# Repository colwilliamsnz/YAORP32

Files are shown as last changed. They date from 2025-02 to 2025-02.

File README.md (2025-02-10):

# YAORP32
 
## Yet Another Open Reflow Plate

A design for a solder reflow plate for SMD rework using commonly available aluminium 400W PTC (positive-temperature-coefficient) heating plate from AliExpress. Temperature is
determined using a K type thermocouple and read using a MAX6675/MAX31855. The PTC is driven by an SSR (solid state relay) using PWM and controlled by a PID. An ESP32 S3 Wroom 1 module is at the heart of the design and firmware is written in C++ for Arduino IDE.

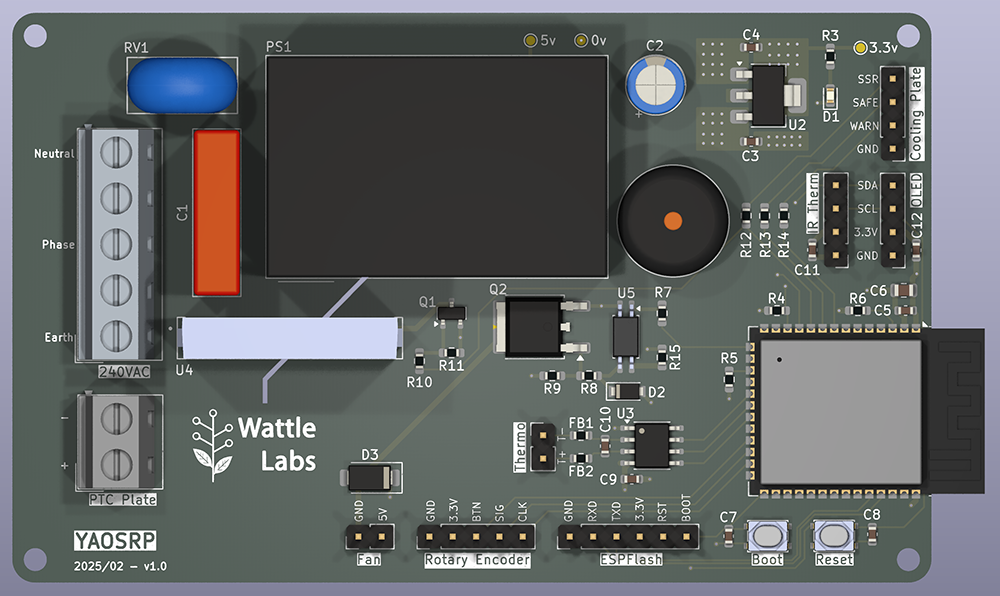
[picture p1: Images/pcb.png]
Prototype


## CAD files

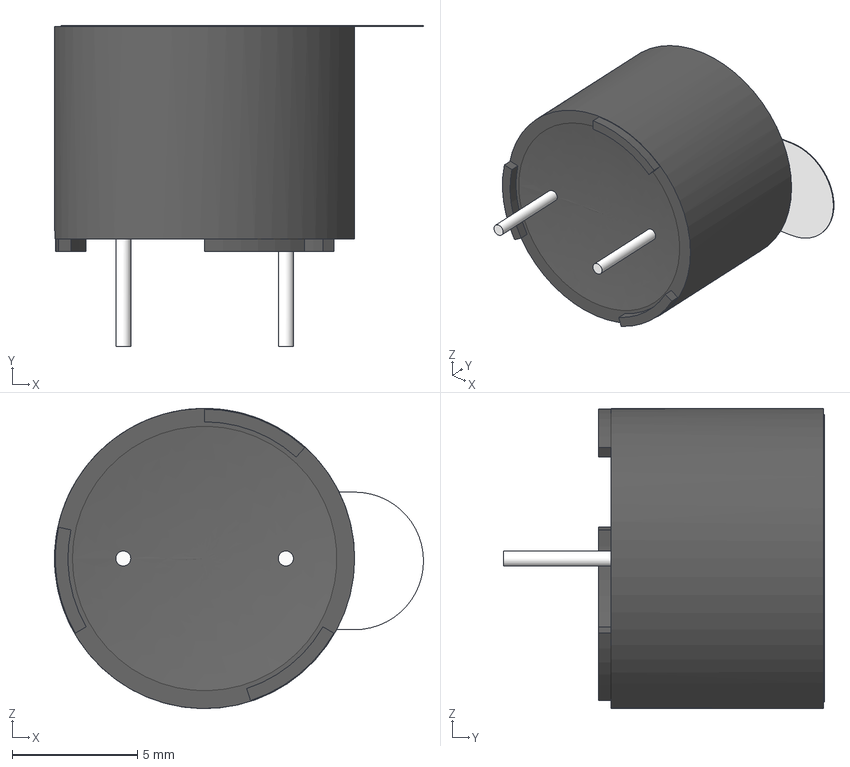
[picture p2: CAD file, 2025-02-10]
KiCad/Controller/Models/AT-1224-TWT-5V-2-R.step
14.7 x 12.9 x 12.0 mm

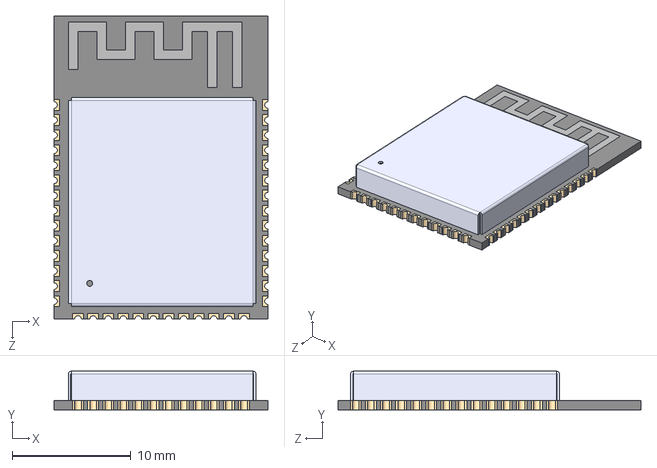
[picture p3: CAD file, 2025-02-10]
KiCad/Controller/Models/ESP32-S3-WROOM-1-N8R2.step
18.0 x 3.25 x 25.5 mm

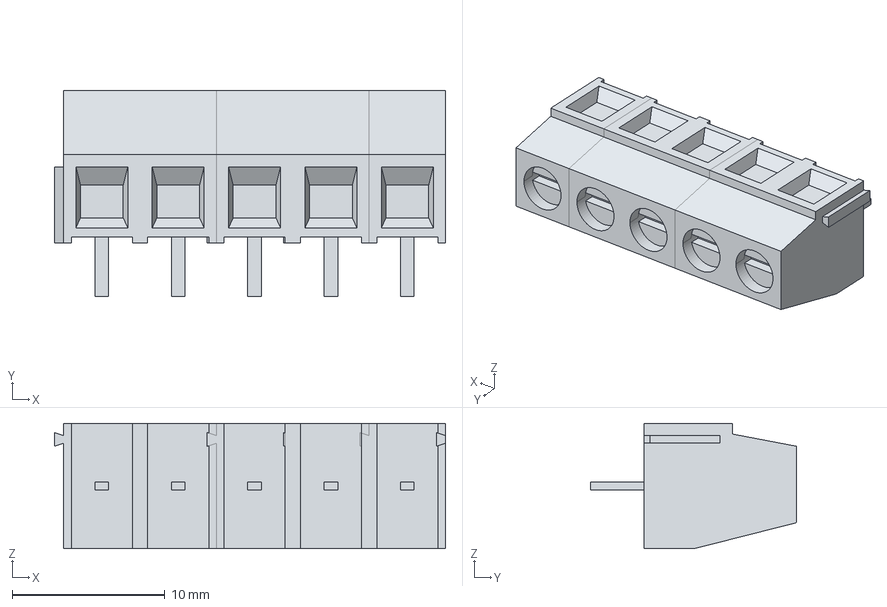
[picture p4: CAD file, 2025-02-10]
KiCad/Controller/Models/Board to Wire x 5.stp.step
25.6 x 13.5 x 8.20 mm
C-282836-2
C-282836-003
C-282836-004

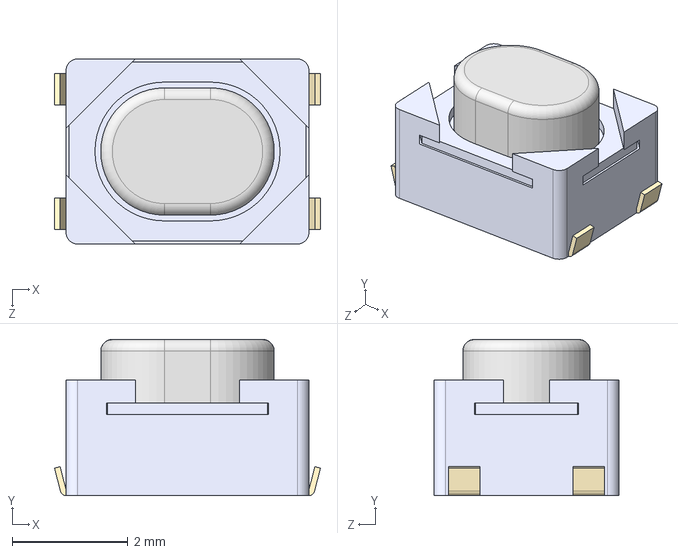
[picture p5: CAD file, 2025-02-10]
KiCad/Controller/Models/Switch_PTS810SJS250SMTR LFS.STEP
4.60 x 2.70 x 3.20 mm

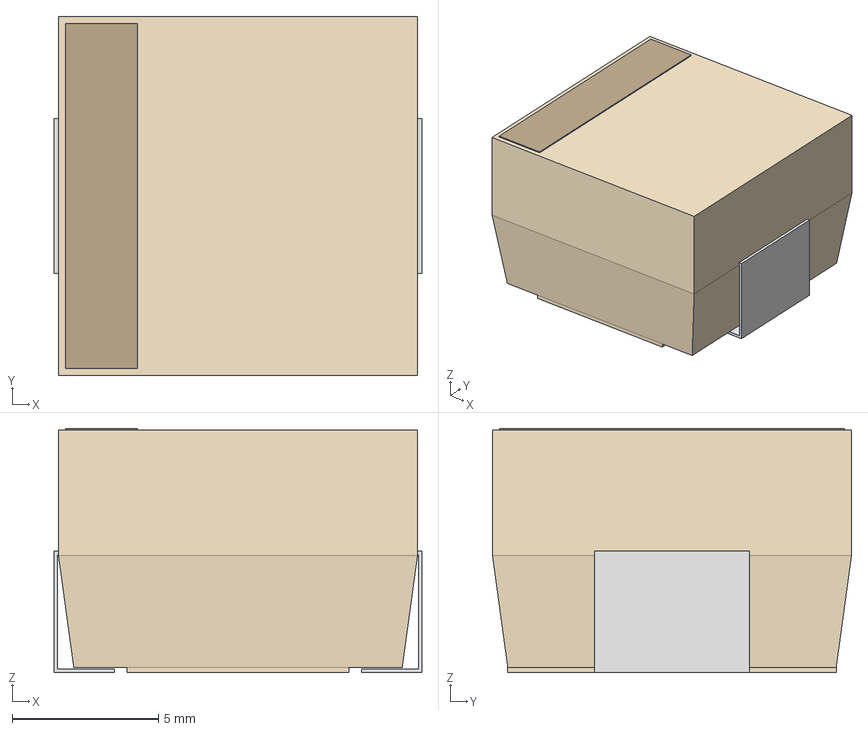
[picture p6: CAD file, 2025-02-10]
KiCad/Controller/Models/IND_770331_WRE.step
12.6 x 12.3 x 8.36 mm

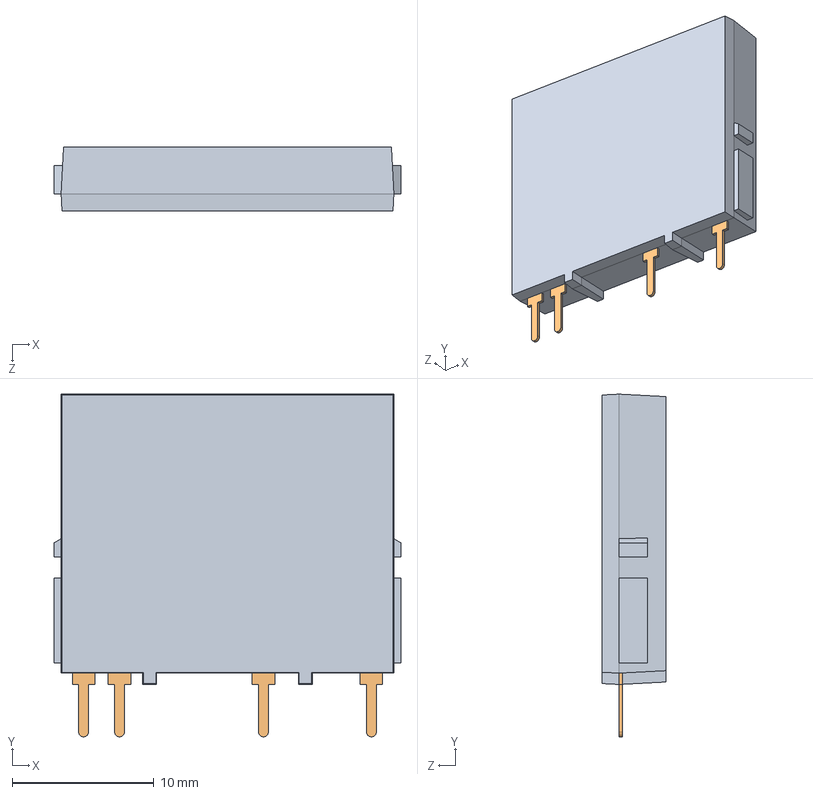
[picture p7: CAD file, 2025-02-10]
KiCad/Controller/Models/SSR_AQG22105.step
24.5 x 24.2 x 4.50 mm
Pin1
Pin2
Pin3
Pin4

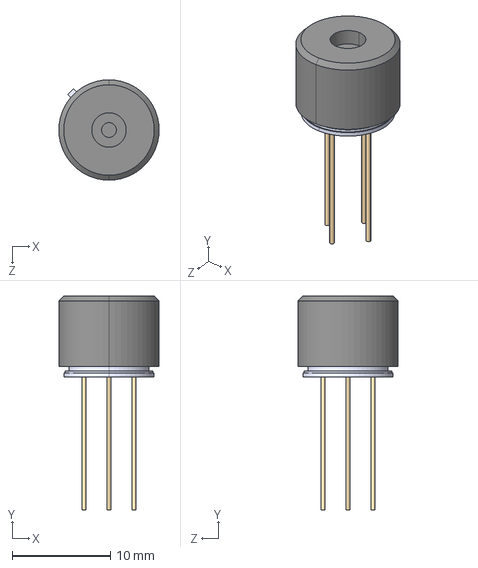
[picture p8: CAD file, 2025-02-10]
KiCad/Controller/Models/IRLED_MLX90614ESF-BCC-000-TU.STEP
10.2 x 21.8 x 10.2 mm

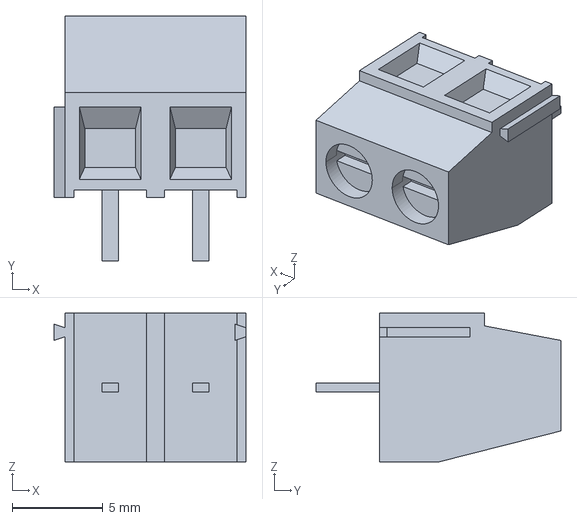
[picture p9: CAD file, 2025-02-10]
KiCad/Controller/Models/Board to Wire x 2.stp
10.6 x 13.5 x 8.20 mm

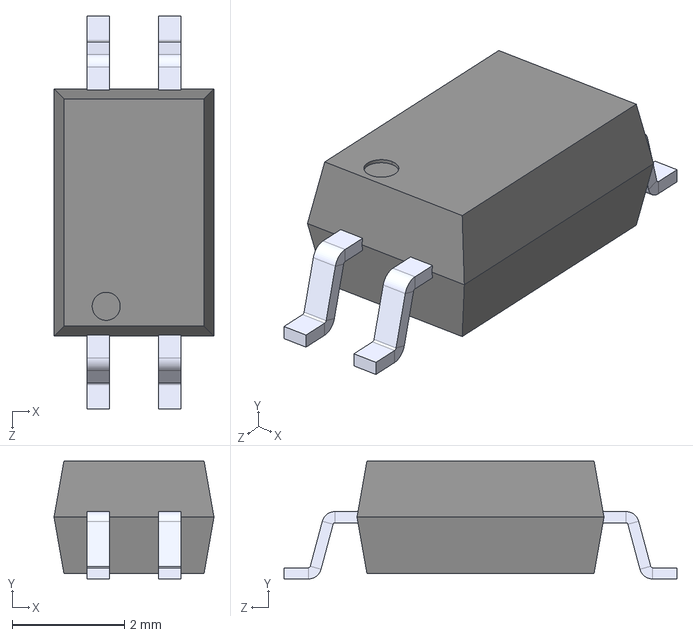
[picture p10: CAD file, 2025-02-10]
KiCad/Controller/Models/Optocoupler_VOS615A-2X001T.step
2.85 x 2.10 x 7.00 mm

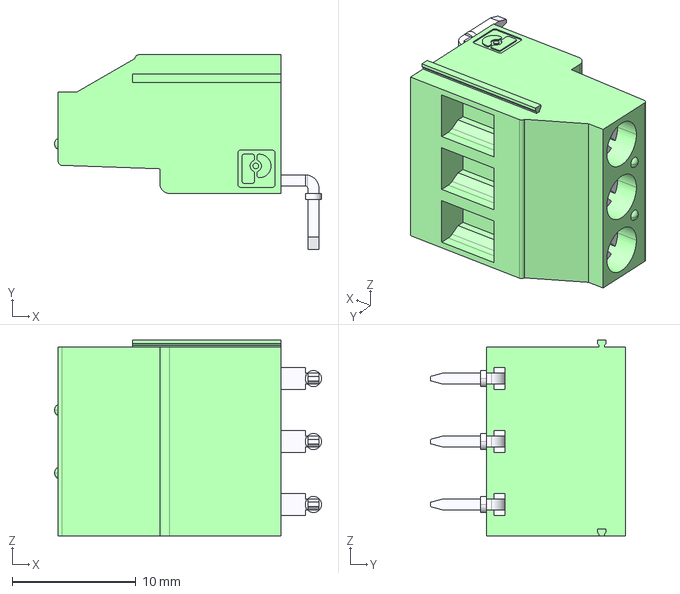
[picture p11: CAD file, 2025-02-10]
KiCad/Controller/Models/Screw_Terminal_3_1712737.stp
21.5 x 15.7 x 15.8 mm

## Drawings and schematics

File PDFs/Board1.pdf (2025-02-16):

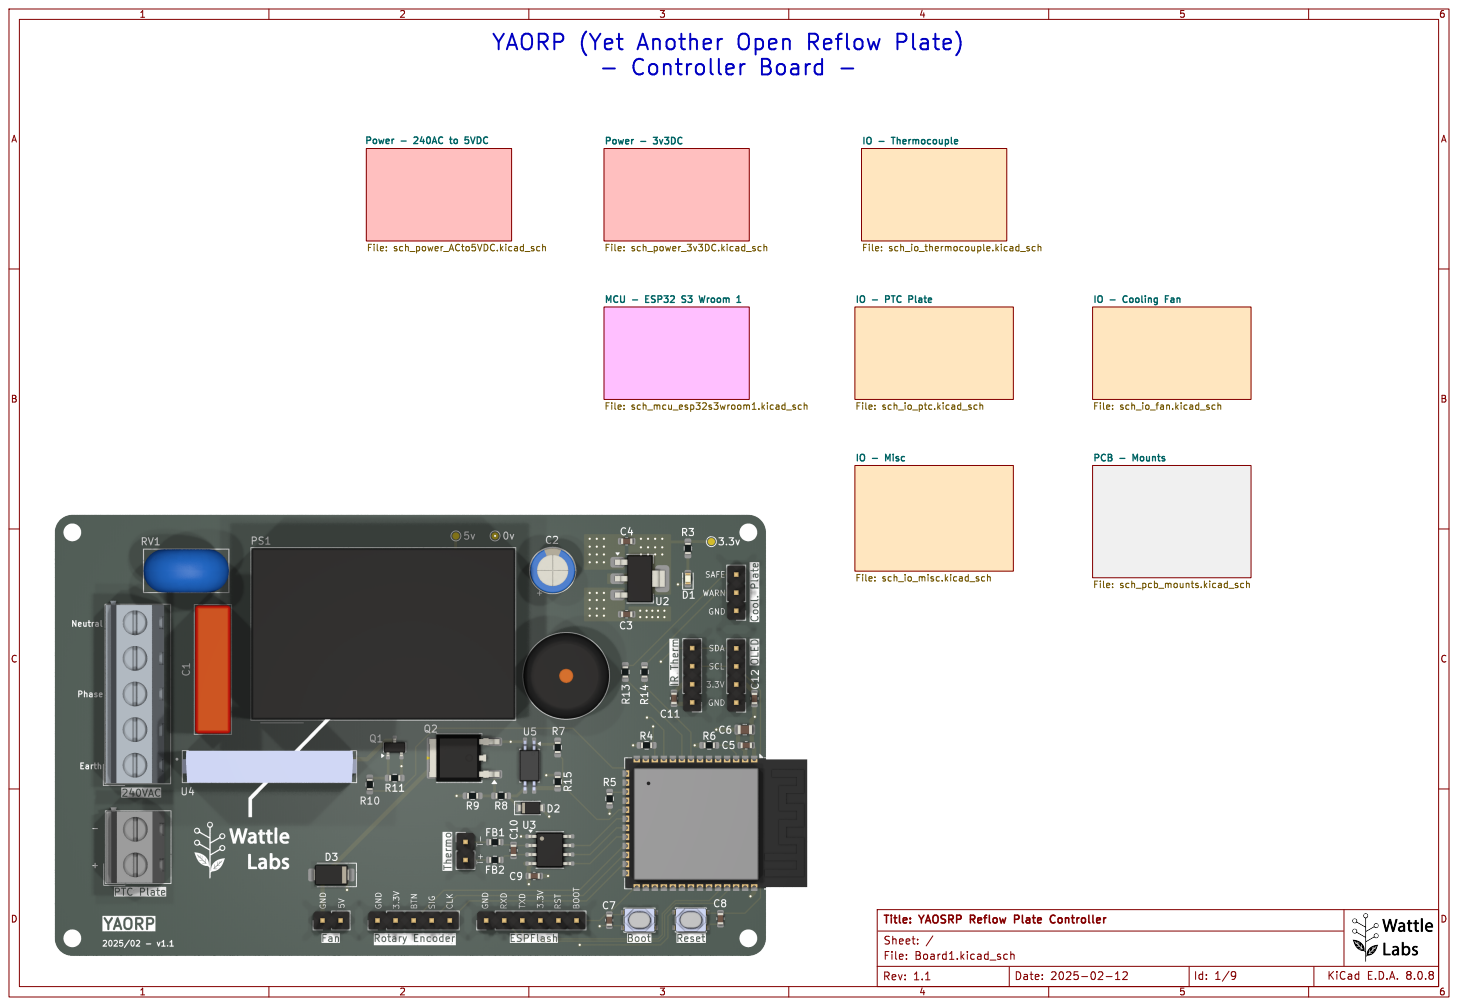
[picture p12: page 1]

IO - Misc File: sch_io_misc.kicad_sch MCU - ESP32 S3 Wroom 1 File: sch_mcu_esp32s3wroom1.kicad_sch

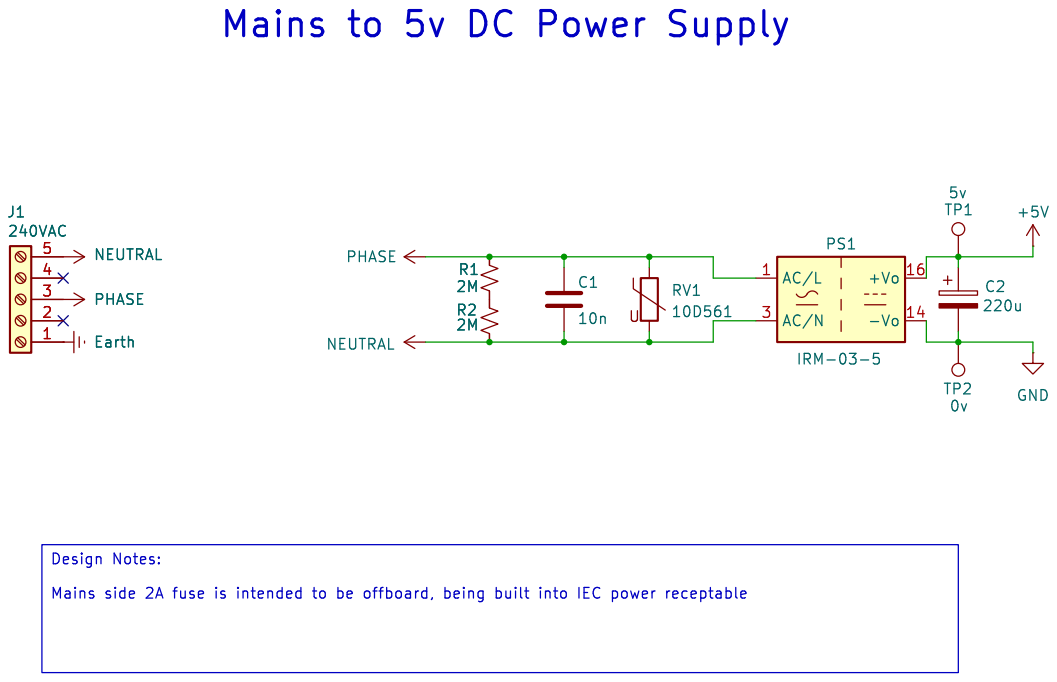
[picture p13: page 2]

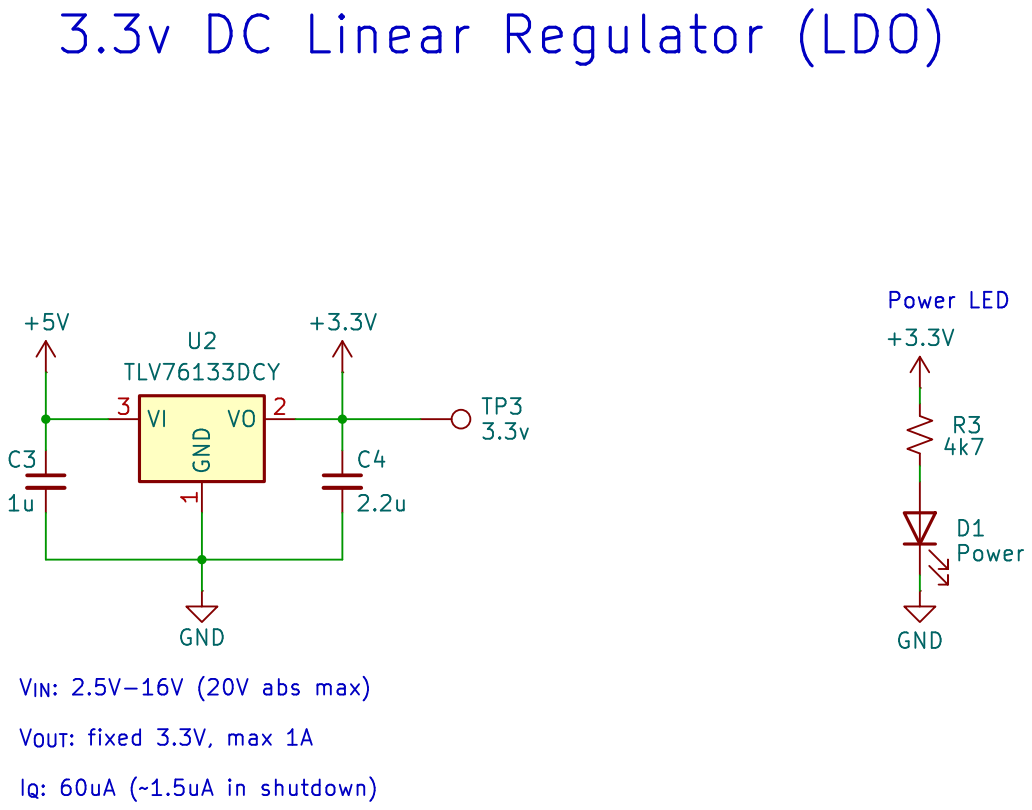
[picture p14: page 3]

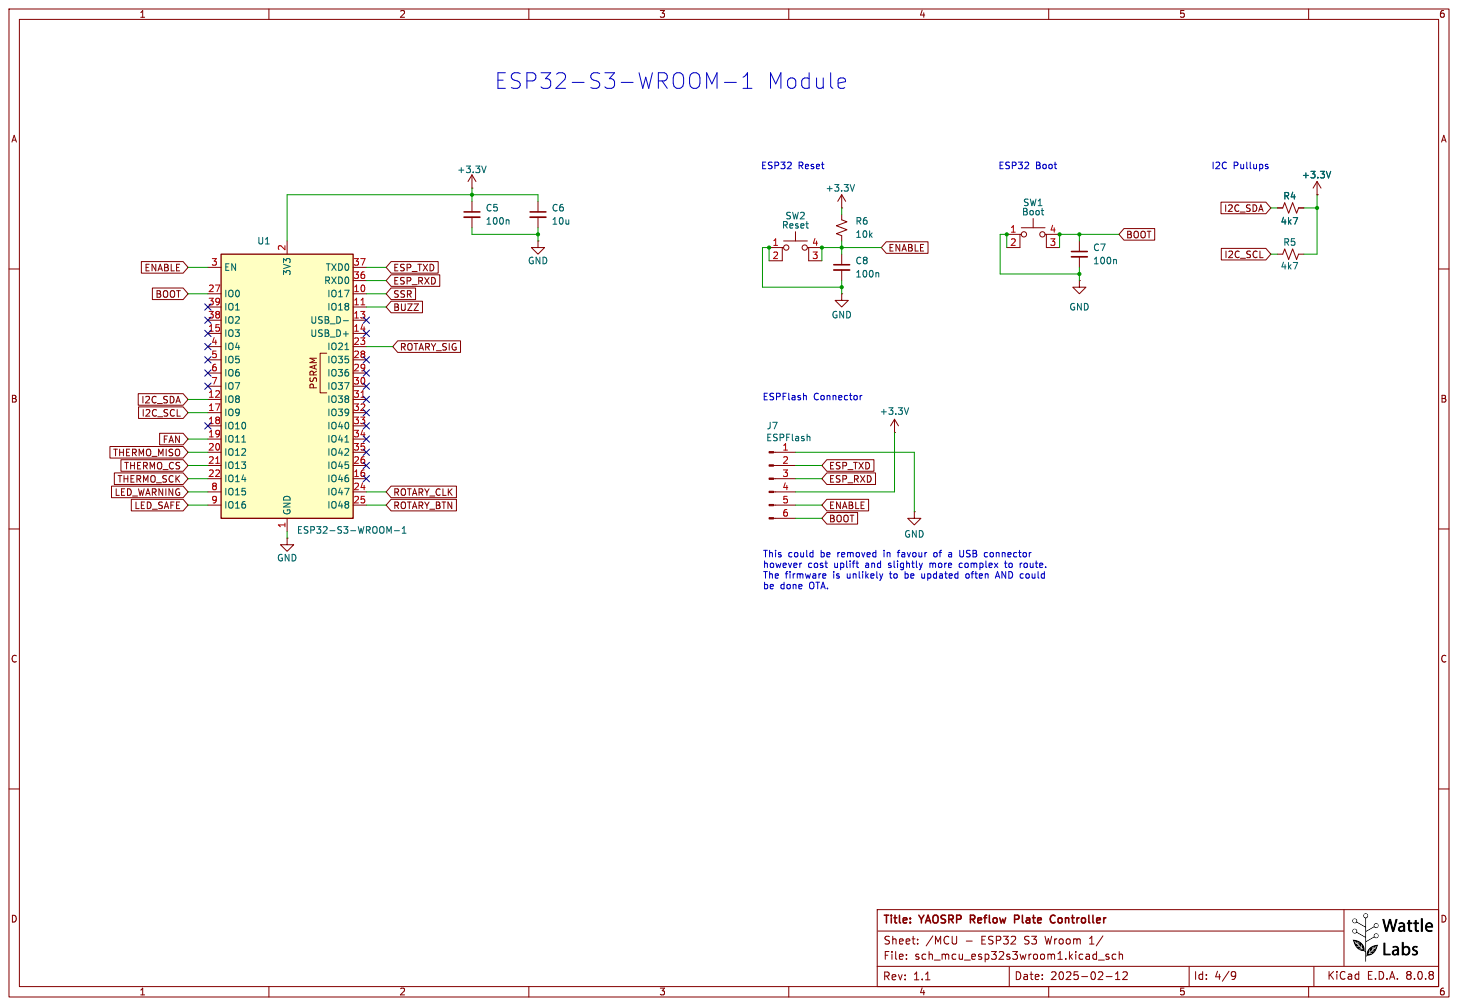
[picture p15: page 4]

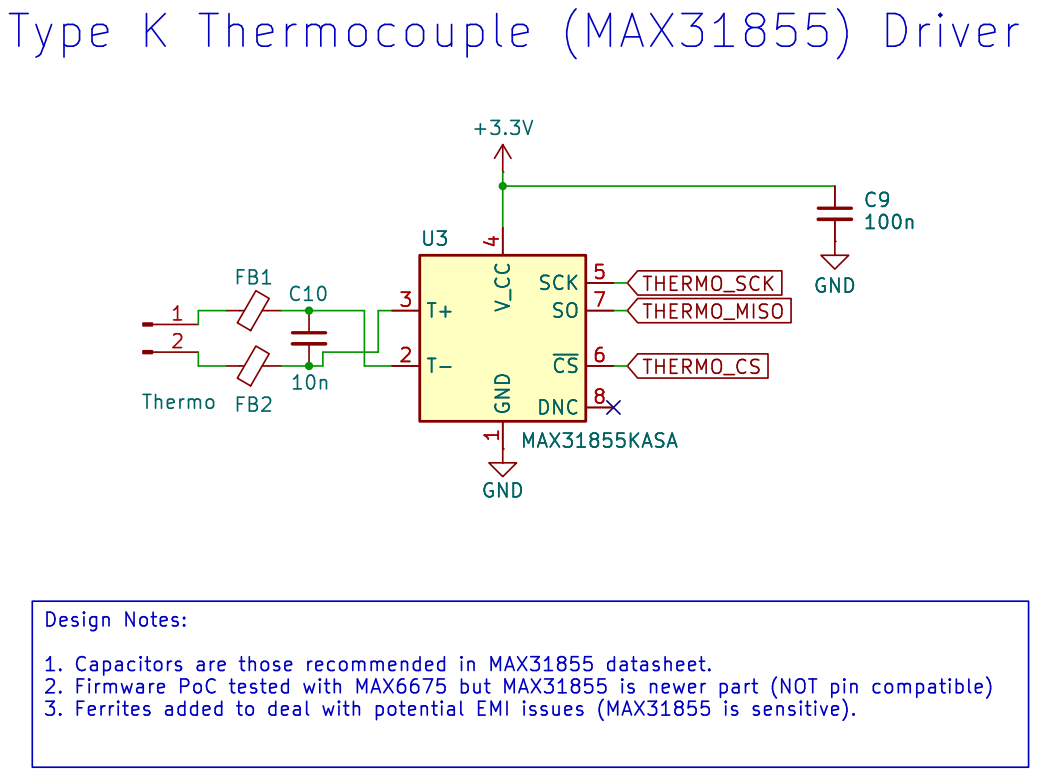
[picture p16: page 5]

4 SCK 5 ~{CS}6 SO 7 DNC 8 U3 MAX31855KASA C10

4 SCK 5 ~{CS}6 SO 7 DNC 8

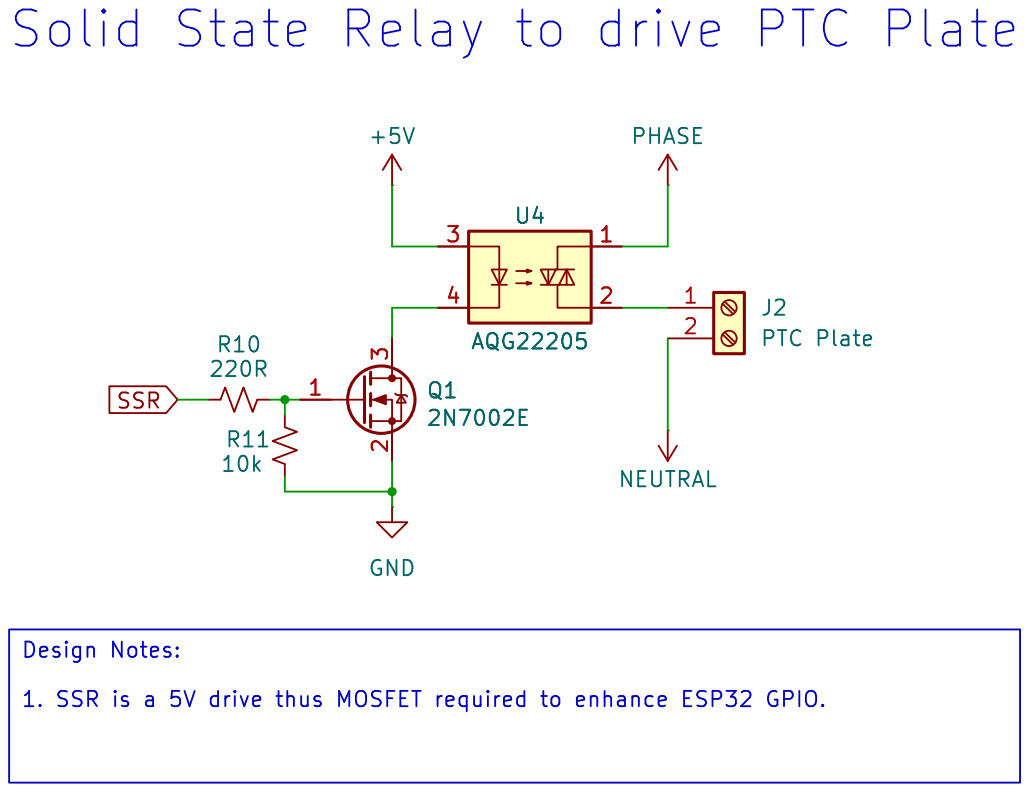
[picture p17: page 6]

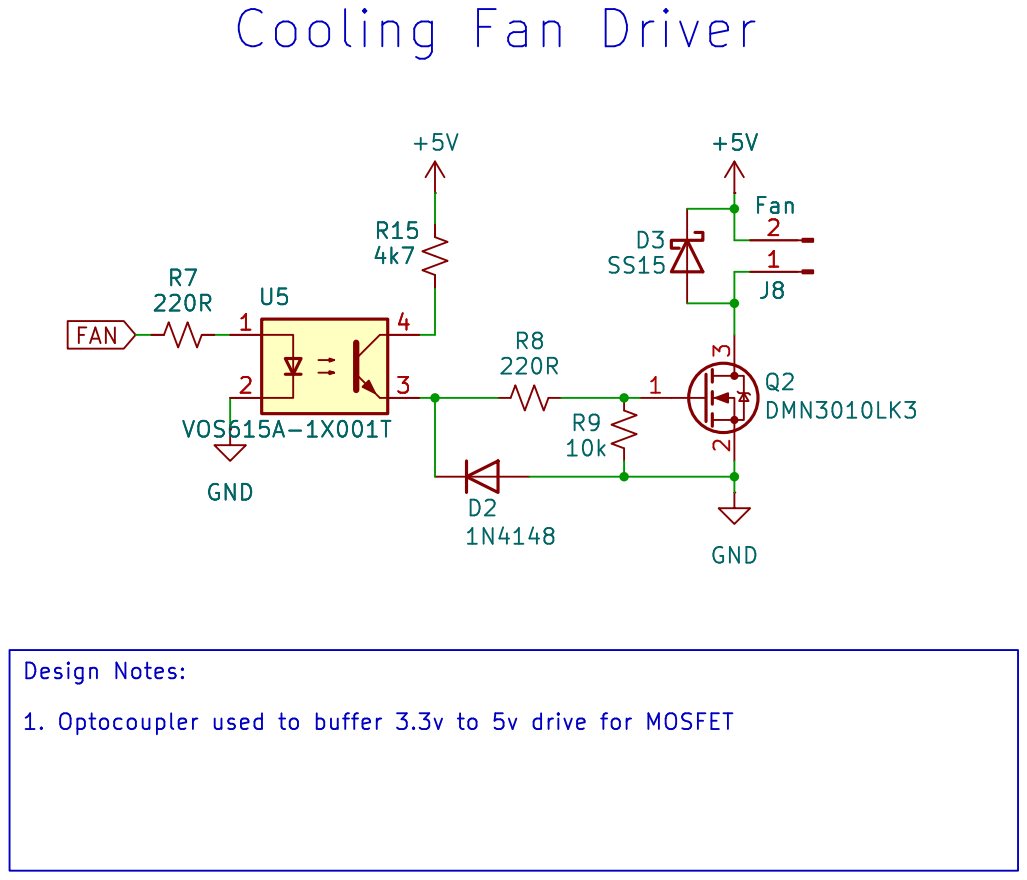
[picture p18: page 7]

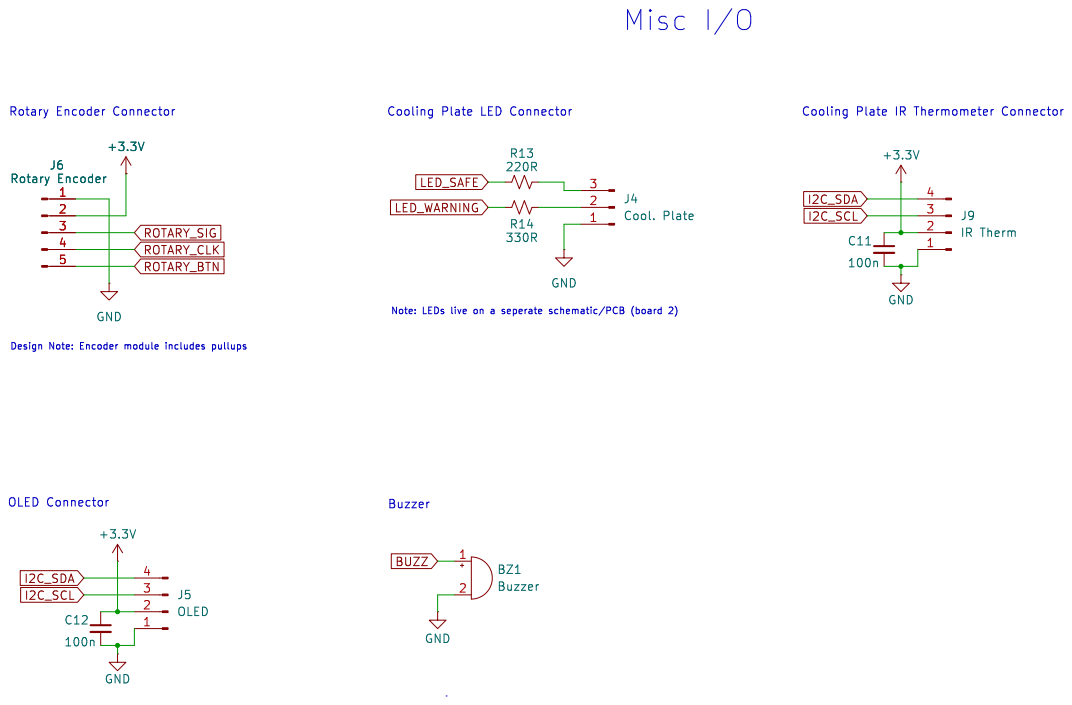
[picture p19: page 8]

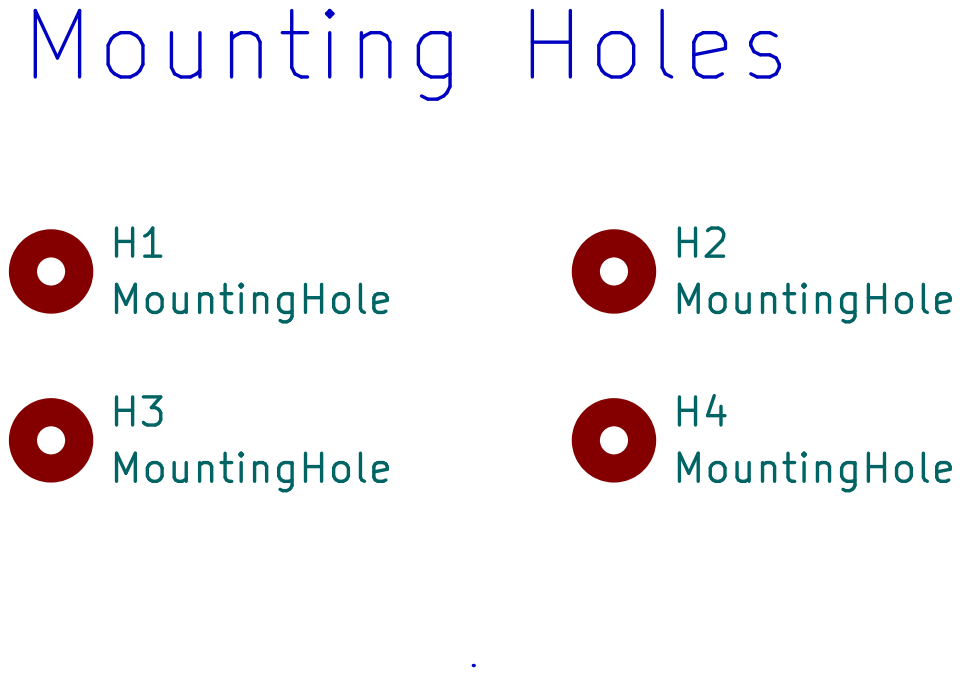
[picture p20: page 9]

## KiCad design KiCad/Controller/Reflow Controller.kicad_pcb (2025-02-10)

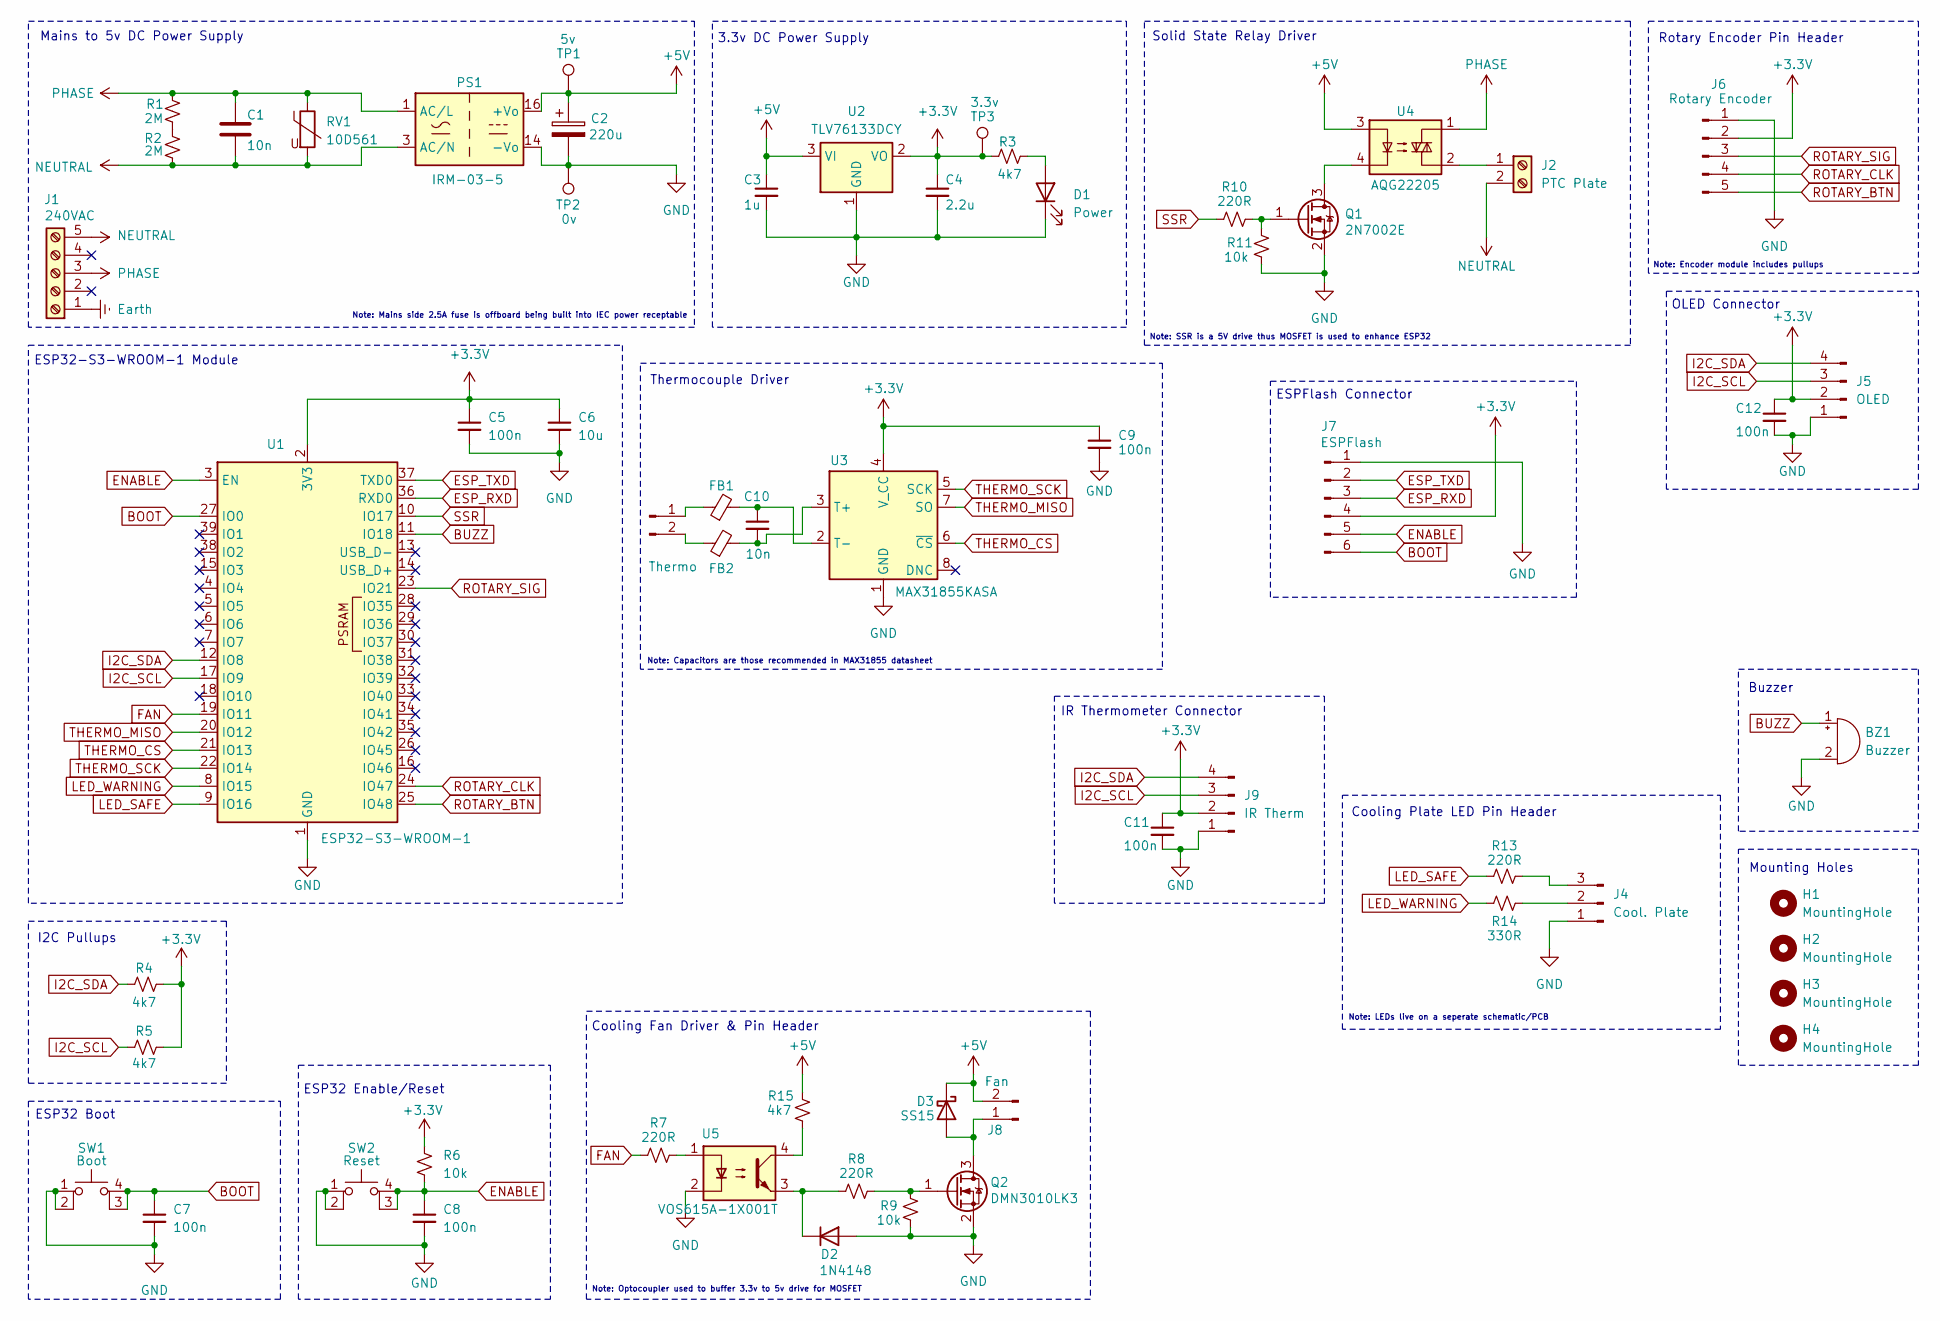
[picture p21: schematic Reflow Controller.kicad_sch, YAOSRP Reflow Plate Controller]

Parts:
BZ1: Buzzer; Buzzer_12x9.5RM7.6; Digikey_PN 668-1470-ND
C1: 10n; C_Rect_L18.0mm_W5.0mm_P15.00mm_FKS3_FKP3
C2: 220u; CP_Radial_D6.3mm_P2.50mm
C3: 1u; C_0603_1608Metric; Digikey_PN 1276-1019-1-ND
C4: 2.2u; C_0603_1608Metric; Digikey_PN 1276-1040-1-ND
C5, C7, C8, C9, C11, C12: 100n; C_0603_1608Metric; Digikey_PN 399-C0603C104K4RACTUCT-ND
C6: 10u; C_0805_2012Metric; Digikey_PN 490-6473-1-ND
C10: 10n; C_0603_1608Metric; Digikey_PN 311-3369-1-ND
D1: Power; LED_0603_1608Metric; Digikey_PN 732-4978-1-ND
D2: 1N4148; Nexperia_CFP3_SOD-123W; Digikey_PN 1N4148W-FDICT-ND
D3: SS15; D_SMA; Digikey_PN SS15FSCT-ND
FB1, FB2: 470R 1LN; R_0603_1608Metric; Digikey_PN BLM18PG471SN1D
H1, H2, H3, H4: MountingHole; MountingHole_2.5mm
J1: 240VAC; Altech_AK100_1x05_P5.00mm
J2: PTC Plate; Altech_AK100_1x02_P5.00mm
J3: Thermo; PinHeader_1x02_P2.54mm_Vertical
J4: Cool. Plate; PinHeader_1x03_P2.54mm_Vertical
J5: OLED; PinHeader_1x04_P2.54mm_Vertical
J6: Rotary Encoder; PinHeader_1x05_P2.54mm_Vertical
J7: ESPFlash; PinHeader_1x06_P2.54mm_Vertical
J8: Fan; PinHeader_1x02_P2.54mm_Vertical
J9: IR Therm; PinHeader_1x04_P2.54mm_Vertical
PS1: IRM-03-5; Converter_ACDC_MeanWell_IRM-03-xx_THT; Digikey_PN 1866-3020-ND
Q1: 2N7002E; SOT-23; Digikey_PN 2N7002E-ND
Q2: DMN3010LK3; TO-252-2; Digikey_PN 31-DMN3010LK3-13CT-ND
R1, R2: 2M; R_2010_5025Metric_Pad1.40x2.65mm_HandSolder; Digikey_PN 2019-HV732HTTE2004FCT-ND
R3, R4, R5, R15: 4k7; R_0603_1608Metric_Pad0.98x0.95mm_HandSolder; Digikey_PN 541-3993-1-ND
R6, R9, R11: 10k; R_0603_1608Metric_Pad0.98x0.95mm_HandSolder; Digikey_PN 541-10.0KHCT-ND
R7, R8, R10, R13: 220R; R_0603_1608Metric_Pad0.98x0.95mm_HandSolder; Digikey_PN 541-10440-1-ND
R14: 330R; R_0603_1608Metric_Pad0.98x0.95mm_HandSolder; Digikey_PN 541-10456-1-ND
RV1: 10D561; RV_Disc_D12mm_W6.1mm_P7.5mm; Digikey_PN 118-MOV-10D561K-ND
SW1: Boot; SW_SPST_PTS810; Digikey_PN CKN10878CT-ND
SW2: Reset; SW_SPST_PTS810; Digikey_PN CKN10878CT-ND
TP1: 5v; TestPoint_Pad_D1.0mm
TP2: 0v; TestPoint_Pad_D1.0mm
TP3: 3.3v; TestPoint_Pad_D1.0mm
U1: ESP32-S3-WROOM-1; Digikey_PN 1965-ESP32-S3-WROOM-1-N4R2CT-ND
U2: TLV76133DCY; SOT-223-3_TabPin2; Digikey_PN 296-TLV76133DCYRCT-ND
U3: MAX31855KASA; SOIC-8_3.9x4.9mm_P1.27mm; Digikey_PN MAX31855KASA+-ND
U4: AQG22205; SSR_AQG22105; Digikey_PN 255-3752-ND
U5: VOS615A-1X001T; SSOP-4_4.4x2.6mm_P1.27mm; Digikey_PN 751-VOS615A-1X001TCT-ND

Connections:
+3.3V: C4.1, C5.1, C6.1, C9.1, C11.1, C12.1, J5.2, J6.2, J7.4, J9.2, R3.1, R4.1, R5.1, R6.2, TP3.1, U1.2 (3V3), U2.2 (VO), U3.4 (V_CC)
+5V: C2.1, C3.1, D3.1 (K), J8.2, PS1.16 (+Vo), R15.1, TP1.1, U2.3 (VI), U4.3
BOOT: C7.1, J7.6, SW1.3 (K), SW1.4 (A), U1.27 (IO0)
BUZZ: BZ1.1 (+), U1.11 (IO18)
ENABLE: C8.1, J7.5, R6.1, SW2.3 (K), SW2.4 (A), U1.3 (EN)
ESP_RXD: J7.3, U1.36 (RXD0)
ESP_TXD: J7.2, U1.37 (TXD0)
Earth: J1.1
FAN: R7.2, U1.19 (IO11)
GND: BZ1.2 (-), C2.2, C3.2, C4.2, C5.2, C6.2, C7.2, C8.2, C9.2, C11.2, C12.2, D1.1 (K), D2.2 (A), J4.1, J5.1, J6.1, J7.1, J9.1, PS1.14 (-Vo), Q1.2 (S), Q2.2 (S), R9.2, R11.2, SW1.1, SW1.2, SW2.1, SW2.2, TP2.1, U1.1 (GND), U1.40 (GND), U1.41 (GND), U2.1 (GND), U3.1 (GND), U5.2
I2C_SCL: J5.3, J9.3, R5.2, U1.17 (IO9)
I2C_SDA: J5.4, J9.4, R4.2, U1.12 (IO8)
LED_SAFE: R13.2, U1.9 (IO16)
LED_WARNING: R14.2, U1.8 (IO15)
NEUTRAL: C1.2, J1.5, J2.2, PS1.3 (AC/N), R2.2, RV1.2
unnamed: D1.2 (A), R3.2
unnamed: D2.1 (K), R8.2, U5.3
unnamed: D3.2 (A), J8.1, Q2.3 (D)
unnamed: J2.1, U4.2
unnamed: FB1.1, J3.1
unnamed: FB2.1, J3.2
unnamed: J4.2, R14.1
unnamed: J4.3, R13.1
unnamed: Q1.3 (D), U4.4
unnamed: Q1.1 (G), R10.1, R11.1
unnamed: Q2.1 (G), R8.1, R9.1
unnamed: R1.2, R2.1
unnamed: R7.1, U5.1
unnamed: R15.2, U5.4
unnamed: C10.2, FB2.2, U3.3 (T+)
unnamed: C10.1, FB1.2, U3.2 (T-)
PHASE: C1.1, J1.3, PS1.1 (AC/L), R1.1, RV1.1, U4.1
ROTARY_BTN: J6.5, U1.25 (IO48)
ROTARY_CLK: J6.4, U1.24 (IO47)
ROTARY_SIG: J6.3, U1.23 (IO21)
SSR: R10.2, U1.10 (IO17)
THERMO_CS: U1.21 (IO13), U3.6 (~CS)
THERMO_MISO: U1.20 (IO12), U3.7 (SO)
THERMO_SCK: U1.22 (IO14), U3.5 (SCK)

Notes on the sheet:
Cooling Fan Driver & Pin Header
Thermocouple Driver
Solid State Relay Driver
ESP32 Boot
Buzzer
Note: Capacitors are those recommended in MAX31855 datasheet
Rotary Encoder Pin Header
3.3v DC Power Supply
Note: Optocoupler used to buffer 3.3v to 5v drive for MOSFET
ESP32-S3-WROOM-1 Module
I2C Pullups
ESPFlash Connector
Note: SSR is a 5V drive thus MOSFET is used to enhance ESP32
ESP32 Enable/Reset
Mounting Holes
Note: Mains side 2.5A fuse is offboard being built into IEC power receptable
Mains to 5v DC Power Supply
Cooling Plate LED Pin Header
Note: LEDs live on a seperate schematic/PCB
Note: Encoder module includes pullups
OLED Connector
IR Thermometer Connector

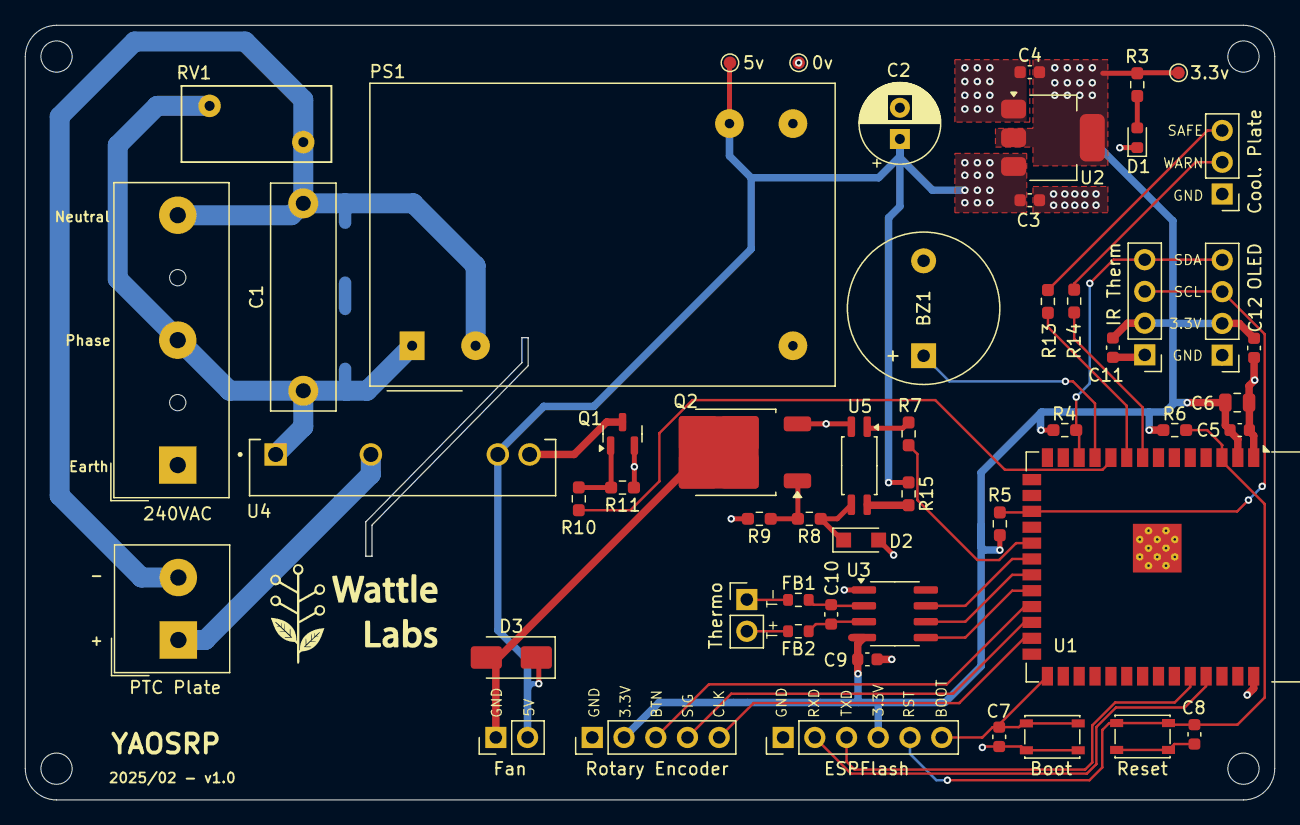
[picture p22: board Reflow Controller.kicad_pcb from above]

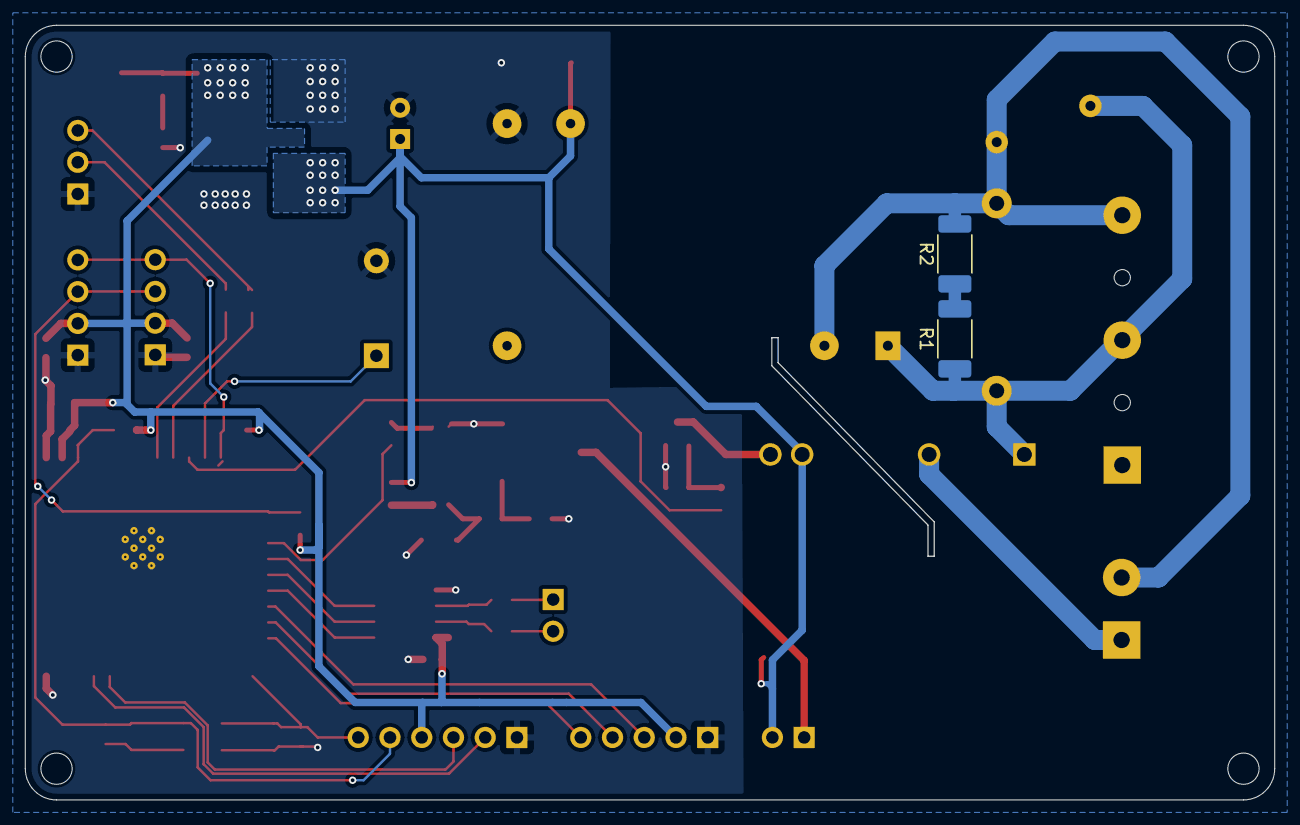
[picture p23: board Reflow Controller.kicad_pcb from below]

Board: 4 copper layers, 100.0 x 62.0 mm, 59 parts (2 on the bottom side), 38 nets.

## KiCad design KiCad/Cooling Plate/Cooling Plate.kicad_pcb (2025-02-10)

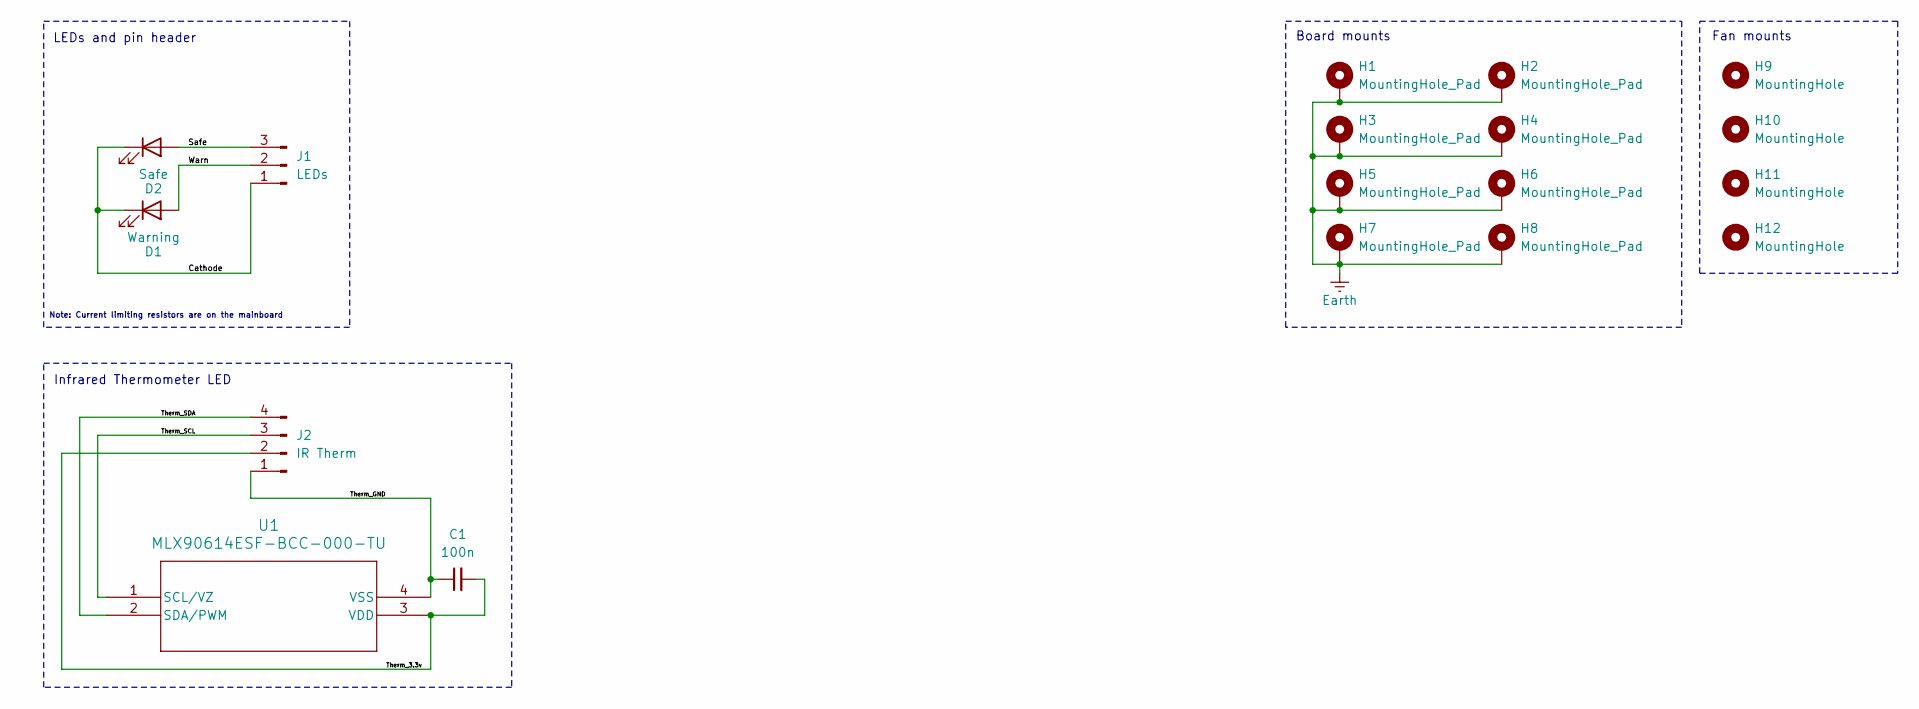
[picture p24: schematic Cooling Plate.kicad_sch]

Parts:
C1: 100n; C_0603_1608Metric; Digikey_PN CC0603KRX7R7BB104
D1: Warning; LED_D3.0mm
D2: Safe; LED_D3.0mm
H1, H2, H3, H4, H5, H6, H7, H8: MountingHole_Pad; MountingHole_2.5mm_Pad_TopBottom
H9, H10, H11, H12: MountingHole; MountingHole_2.5mm
J1: LEDs; PinHeader_1x03_P2.54mm_Horizontal
J2: IR Therm; PinHeader_1x04_P2.54mm_Horizontal
U1: MLX90614ESF-BCC-000-TU; MLX90614xCC_MEL; Digikey_PN MLX90614ESF-BCC-000-TU-ND

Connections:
/Cathode: D1.1 (K), D2.1 (K), J1.1
/Safe: D2.2 (A), J1.3
/Therm_3.3v: C1.2, J2.2, U1.3 (VDD)
/Therm_GND: C1.1, J2.1, U1.4 (VSS)
/Therm_SCL: J2.3, U1.1 (SCL/VZ)
/Therm_SDA: J2.4, U1.2 (SDA/PWM)
/Warn: D1.2 (A), J1.2
Earth: H1.1, H2.1, H3.1, H4.1, H5.1, H6.1, H7.1, H8.1

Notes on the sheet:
Fan mounts
LEDs and pin header
Note: Current limiting resistors are on the mainboard
Board mounts
Infrared Thermometer LED

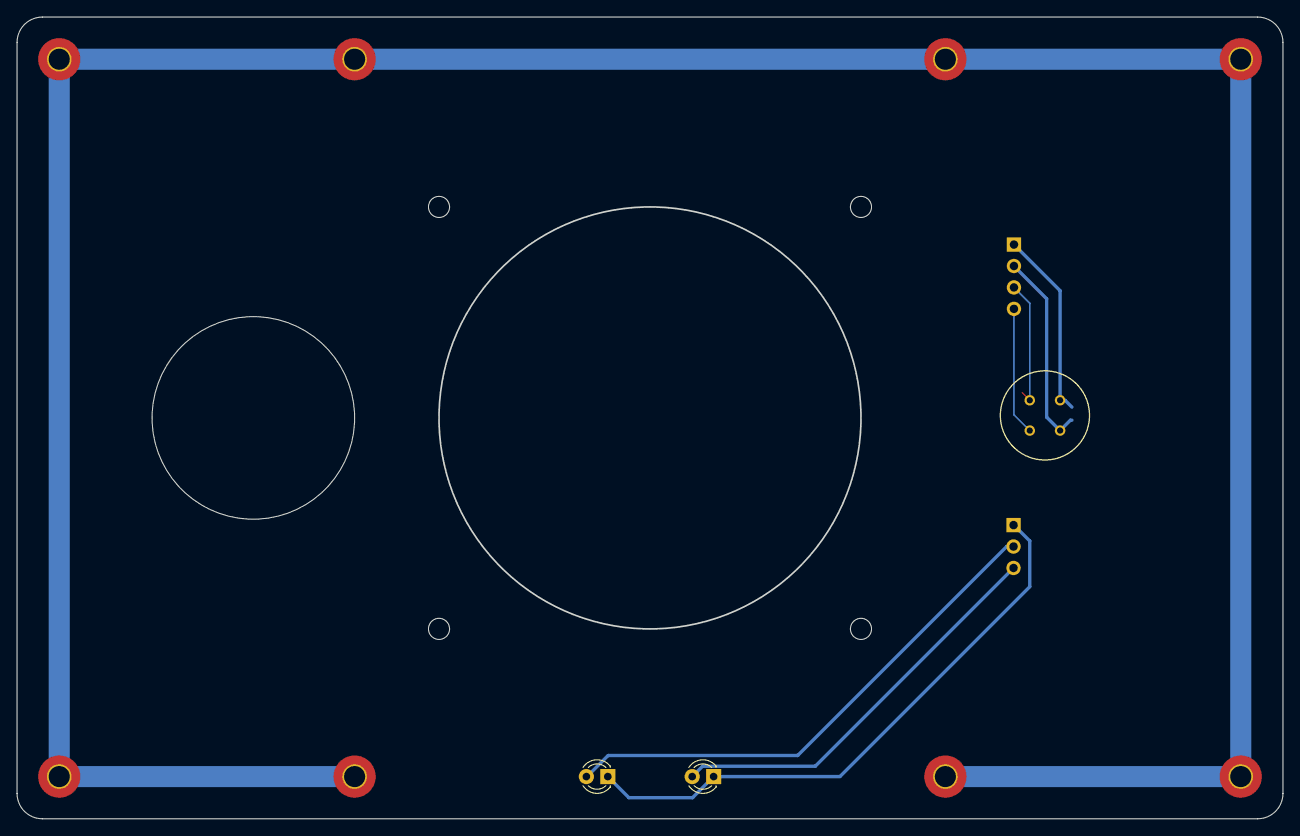
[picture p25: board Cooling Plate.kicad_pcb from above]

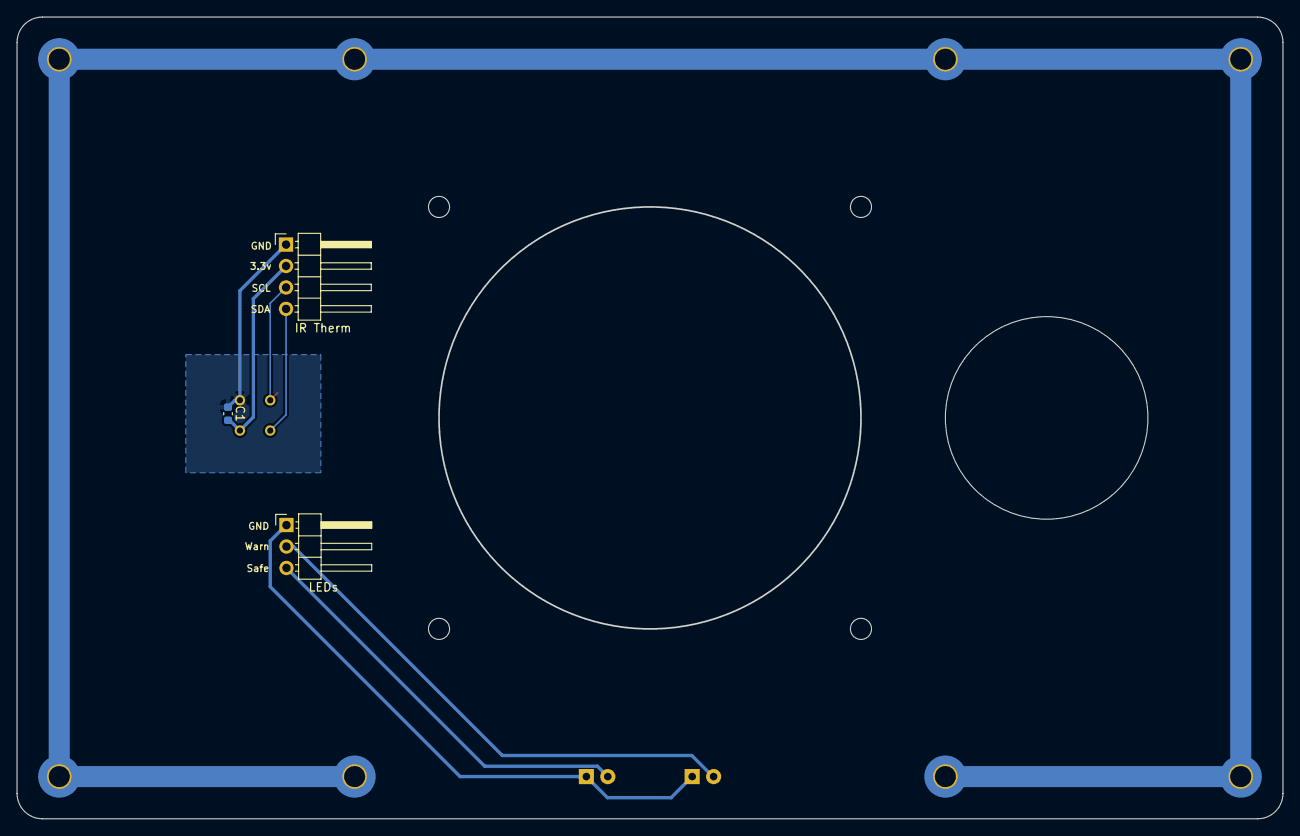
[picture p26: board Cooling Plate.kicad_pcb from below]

Board: 2 copper layers, 150.0 x 95.0 mm, 18 parts (3 on the bottom side), 8 nets.

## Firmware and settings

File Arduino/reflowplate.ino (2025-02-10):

/* ---================================YAORP32 v0.1 ==================================---
Software to drive Wattle Labs YAORP32 (Yet Another Open Reflow Plate) based on ESP32 S3
and commonly available aluminium 400W PTC heating plates from AliExpress. Temperature is
determined using a K type thermocouple and read using a MAX6675. The PTC is driven by an
SSR using PWM and controlled by a PID.

Initial 0.1 release for testing and circuit board design purposes. Future improvements may
implement selectable reflow curves. For now the reflow temp can be changed in the UI and
the single curve in the code using "temp_preheat" variable.
*/

/* --- To do ---
1. Add confirmation sound(s) when each phase completes. Maybe a pip to represent each phase
2. Add a safety timer that will shutdown the PID/Hotplate if the elapsed time exceeds a value
*/

// Native libraries
#include <Arduino.h>
#include <Wire.h>

#include "driver/ledc.h" // ESP32 library for hardware timers (for LED flashing, and SSR PWM)

// Third party libraries
#include <U8g2lib.h> // Graphics library for OLED screen - https://github.com/olikraus/u8g2
#include "max6675.h" // MAX6675 thermocouple library - https://github.com/adafruit/MAX6675-library
#include <AutoPID.h> // PID libary - https://ryand.io/AutoPID/
#include "avdweb_Switch.h" // Switch library for debounce and hold function - https://github.com/avdwebLibraries/avdweb_Switch
#include <Rotary.h> // Rotary encoder library

// UI image resources
#include "logos.h"

// I2C GPIO connections for OLED display (SSD1306)
#define PIN_I2C_SDA 21
#define PIN_I2C_SCL 22

// Ancillary GPIO connections for SSR, Buzzer, indicator LEDs
#define PIN_SSR 33
#define PIN_BUZZER 27
#define PIN_LED_SAFE 4
#define PIN_LED_WARN 15

// SPI GPIO connections for MAX6675 Thermocouple Converter
#define PIN_THERMO_SDO 19
#define PIN_THERMO_CS 23
#define PIN_THERMO_SCK 5

// Rotary encoder GPIO connections
#define PIN_ROTARY_CLK 14  // rotary encoder CLK pin
#define PIN_ROTARY_SIG 13  // rotary encoder SIG pin
#define PIN_ROTARY_BUT 26  // press and hold button > 1s to "select"

// PID settings and gains
#define OUTPUT_MIN 0
#define OUTPUT_MAX 255
#define KP 2
#define KI .0025
#define KD 9

/* Try these :)
#define KP .12
#define KI .0003
#define KD 0
*/

#define TEMP_READ_DELAY 250    // Delay in ms to take temperature readings. Max6675 allows only every ~250ms
#define SCREEN_DRAW_DELAY 500  // Delay in ms to update the OLED display.

// Variables /////////////////////////////////////////////////////////////////
unsigned long lastTempUpdate;    //tracks time of last temp update
unsigned long lastScreenUpdate;  //tracks time of last screen update
unsigned long lastTimerUpdate;   // tracks timer of last timer update

int timerMode;  // used to track how long to spend in each mode once temperature is reached by the PID

double temperature, setTemp, outputVal;
double temp_preheat = 150;
double temp_reflow = 200;
int mode;  // 0 = Idle, 1 = Preheat, 2 = Soak, 3 = Reflow
int screen;
char *modeDescription = "";

bool boolAtSetPoint = false;
/////////////////////////////////////////////////////////////////////////////

// Instansiate SSD1306 display object
U8G2_SSD1306_128X64_NONAME_F_HW_I2C u8g2(U8G2_R0, PIN_I2C_SCL, PIN_I2C_SDA, U8X8_PIN_NONE);

// Instantiate MAX6675 thermocouple object
MAX6675 thermocouple(PIN_THERMO_SCK, PIN_THERMO_CS, PIN_THERMO_SDO);

// Instantiate AutoPID object
// input/output variables passed by reference, so they are updated automatically
AutoPID myPID(&temperature, &setTemp, &outputVal, OUTPUT_MIN, OUTPUT_MAX, KP, KI, KD);

// Instantiate rotary encoder rotation detection/debounce object - library "Rotary"
Rotary rotary = Rotary(PIN_ROTARY_CLK, PIN_ROTARY_SIG);

// Instantiate rotary encoder switch debounce object - library "AVDWeb_Switch"
Switch pushButton = Switch(PIN_ROTARY_BUT, INPUT_PULLUP, LOW, 1);

void setup() {
  Serial.begin(115200);
  Serial.println(F("Debug started..."));

  // Setup ledc channels for PWM control of SSR, warning LEDs, and sound output
  // Note the channel set-up was required to ensure SSR PWM freq. = 1kHz. Any other channels resulted in 1Hz and disruption of sound output
  ledcAttachChannel(PIN_SSR, /*PWM_FREQUENCY*/ 1000, /*PWM_RESOUTION */8, /*CHANNEL*/ 7); // 1000Hz needed to drive the plate to full temperatures!
  ledcAttachChannel(PIN_LED_WARN, /*PWM_FREQUENCY=*/4, /*PWM_RESOUTION=*/8, 1);  // 4Hz = lowest freq. hardware timer runs at. 8bit means values 0-255. Channel 1.
  ledcAttachChannel(PIN_LED_SAFE, /*PWM_FREQUENCY=*/4, /*PWM_RESOUTION=*/8, 2);
  ledcAttachChannel(PIN_BUZZER, /*PWM_FREQUENCY=*/4, /*PWM_RESOUTION=*/8, 4);

  // Setup PID
  myPID.setBangBang(30); // Bang bang set to > 30 below setpoint (0 to turn off)
  myPID.setTimeStep(TEMP_READ_DELAY);  // set PID update freq. to same as temperature sensor

  // Ensure status LEDs reflect startup temperature!
  temperature = thermocouple.readCelsius(); // Get plate temperature. We get it directly rather than through the function to mitigate startup delay showing incorrect warning LED status
  updateLEDs(); // Update LEDs based on plate temperature
  
  ui_boot();  // Display boot screen

  disableSSR();  // Ensure the SSR is turned off at boot

  mode = 0;  // Start in idle mode
  screen = 0; // Start in temp monitoring screen
}

void loop() {
  processEncoder(); // Process the rotary encoder

  getTemperature();  // Get temperature from thermocouple

  updateLEDs();  // Update LEDs based on plate temperature

  updateUI();  // Draw appropriate screen

  processModes(); // Pre-heat, soak, reflow...
}

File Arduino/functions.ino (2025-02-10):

//call repeatedly in loop, only updates after a certain time interval
//returns true if update happened
bool getTemperature() {
  if ((millis() - lastTempUpdate) > TEMP_READ_DELAY) {
    temperature = thermocouple.readCelsius();
    lastTempUpdate = millis();
    return true;
  }
  return false;
}

void updateTimer() {
  if ((millis() - lastTimerUpdate) > 1000) {
    if (timerMode > 0) {
      timerMode = timerMode - 1;
      lastTimerUpdate = millis();
      Serial.println(timerMode);
    }
  }
}

// Status LEDs
void updateLEDs() {
  if (temperature > 40 && temperature < 80) {
    ledc_stop(LEDC_HIGH_SPEED_MODE, LEDC_CHANNEL_2, 0);  // stop flashing SAFE LED
    ledcWrite(PIN_LED_WARN, 255);                        // set WARN LED to 100% duty cycle
  } else if (temperature > 80) {
    ledc_stop(LEDC_HIGH_SPEED_MODE, LEDC_CHANNEL_2, 0);  // stop flashing WARN LED
    ledcWrite(PIN_LED_WARN, 128);                        // set SAFE LED to 100% duty cycle
  } else {
    ledc_stop(LEDC_HIGH_SPEED_MODE, LEDC_CHANNEL_1, 0);  // stop flashing WARN LED
    ledcWrite(PIN_LED_SAFE, 255);                        // set SAFE LED to 100% duty cycle
  }
}

void disableSSR() {
  setTemp = 0;
  ledc_stop(LEDC_HIGH_SPEED_MODE, LEDC_CHANNEL_7, 0);
}

void updateSSR(double PWM) {
  ledcWrite(PIN_SSR, PWM);
}

void processModes() {
  // Idle
  if (mode == 0) {  // Idle mode
    disableSSR();
    timerMode = 0;
    modeDescription = "Idle";
  }

  // Preheat to soak
  if (mode == 1) {
    modeDescription = "Preheat";
    setTemp = temp_preheat;

    myPID.run();

    updateSSR(outputVal);

    if (myPID.atSetPoint(2)) {
      timerMode = 90;  // start countdown timer 90s
      mode = 2;        // Soak mode
    }
  }

  // Soak
  if (mode == 2) {
    modeDescription = "Soak";

    myPID.run();

    updateSSR(outputVal);

    if (myPID.atSetPoint(2)) {
      boolAtSetPoint = true;  // only start the timer if we reached the setpoint
    }

    if (boolAtSetPoint) {
      updateTimer();
    }

    // Soak countdown timer is complete, move to reflow
    if (timerMode == 0) {
      timerMode = 15;  // start
      mode = 3;        // Reflow mode
      boolAtSetPoint = false;
    }
  }

  // Reflow
  if (mode == 3) {
    modeDescription = "Reflow";
    setTemp = temp_reflow;

    myPID.run();

    updateSSR(outputVal);

    if (myPID.atSetPoint(2)) {
      boolAtSetPoint = true;  // only start the timer if we reached the setpoint
    }

    if (boolAtSetPoint) {
      updateTimer();
    }

    if (timerMode == 0) {  // reflow is finished, revert to idle mode
      mode = 0;
      screen = 0;
      boolAtSetPoint = false;
    }
  }
}

void processEncoder() {
  // Poll rotary encoder and pushbutton /////////////////////////////////////////
  unsigned char result = rotary.process();
  pushButton.poll();

  // process rotary encoder inputs only when in the temperature select screen ///
  if (screen == 1 && result == DIR_CW && (temp_reflow < 220)) {
    temp_reflow += 5;
    soundClick();
  }

  if (screen == 1 && result == DIR_CCW && (temp_reflow > 160)) {
    temp_reflow -= 5;
    soundClick();
  }

  // Process long press as appropriate
  if (pushButton.longPress()) {
    if (screen == 0) {
      screen = 1;
      soundConfirm();
    } else if (screen == 1) {
      screen = 2;
      mode = 1;
      soundConfirm();
    } else if (screen == 2) {
      screen = 0;
      mode = 0;
      soundCancel();
    }
  }
}

void updateUI() {
  if ((millis() - lastScreenUpdate) > SCREEN_DRAW_DELAY) {

    if (screen == 0) {
      ui_idle(temperature);
    }

    if (screen == 1) {
      ui_temp();
    }

    if (screen == 2) {
      ui_heating(modeDescription, setTemp, temperature, timerMode);
    }

    lastScreenUpdate = millis();
  }
}

void soundBoot() {
  // Play startup sound
  ledcWriteTone(PIN_BUZZER, 1000);
  delay(250);
  ledcWriteTone(PIN_BUZZER, 1800);
  delay(180);
  ledcWriteTone(PIN_BUZZER, 0);
}

void soundCancel() {
  // Play cancel sound
  ledcWriteTone(PIN_BUZZER, 1800);
  delay(300);
  ledcWriteTone(PIN_BUZZER, 0);
  delay(50);
  ledcWriteTone(PIN_BUZZER, 1400);
  delay(300);
  ledcWriteTone(PIN_BUZZER, 0);
  delay(50);
  ledcWriteTone(PIN_BUZZER, 1000);
  delay(100);
  ledcWriteTone(PIN_BUZZER, 0);
}

void soundConfirm() {
  ledcWriteTone(PIN_BUZZER, 1800);
  delay(75);
  ledcWriteTone(PIN_BUZZER, 0);
  delay(50);
  ledcWriteTone(PIN_BUZZER, 1800);
  delay(75);
  ledcWriteTone(PIN_BUZZER, 0);
}

void soundClick() {
  ledcWriteTone(PIN_BUZZER, 1800);
  delay(3);
  ledcWriteTone(PIN_BUZZER, 0);
}

void ui_boot() {
  // Render boot screen and play "on" tone from piezo
  u8g2.begin();
  u8g2.enableUTF8Print();

  u8g2.clearBuffer();
  u8g2.setFontMode(1);
  u8g2.setBitmapMode(1);

  u8g2.drawXBMP(12, 0, 37, 64, icon_logo);

  u8g2.setFont(u8g2_font_helvB08_tr);
  u8g2.drawStr(54, 26, "Wattle Labs");
  u8g2.drawStr(57, 41, "YAORP32");

  u8g2.sendBuffer();
  soundBoot();

  delay(2000);
}

void ui_idle(int temp) {
  // Render idle screen showing current plate temperature
  // screen = 1

  char buffer[4] = "";

  u8g2.clearBuffer();
  u8g2.setFontMode(1);
  u8g2.setBitmapMode(1);

  u8g2.setFont(u8g2_font_helvB08_tr);
  u8g2.drawStr(55, 10, "Idle");

  u8g2.drawXBMP(34, 24, 16, 16, icon_temperature);

  itoa(temp, buffer, 10);  // convert int to string

  u8g2.setFont(u8g2_font_profont22_tr);
  u8g2.drawStr(60, 39, buffer);

  u8g2.setFont(u8g2_font_5x8_tr);
  u8g2.drawStr(14, 64, "Hold Select to Start");

  u8g2.sendBuffer();
}

void ui_temp() {
  // Render temperature selection screen
  // screen = 2
  char buffer[4] = "";

  u8g2.clearBuffer();
  u8g2.setFontMode(1);
  u8g2.setBitmapMode(1);

  u8g2.setFont(u8g2_font_helvB08_tr);
  u8g2.drawStr(13, 8, "Select Reflow Temp:");

  u8g2.drawXBMP(34, 24, 16, 16, icon_temperature);

  itoa(temp_reflow, buffer, 10);  // convert int to string

  u8g2.setFont(u8g2_font_profont22_tr);
  u8g2.drawStr(60, 39, buffer);

  u8g2.setFont(u8g2_font_5x8_tr);
  u8g2.drawStr(14, 64, "Hold Select to Start");

  u8g2.sendBuffer();
}

void ui_heating(char *phase, int temp_target, int temp_current, int timer) {
  // Render heating screen showing current phase
  // screen = 3
  char buffer[4] = "";

  u8g2.clearBuffer();
  u8g2.setFontMode(1);
  u8g2.setBitmapMode(1);

  u8g2.setFont(u8g2_font_5x8_tr);
  u8g2.drawStr(12, 64, "Hold Select to Cancel");

  u8g2.drawXBMP(34, 24, 16, 16, icon_temperature);

  itoa(temp_target, buffer, 10);  // convert int to string
  u8g2.setFont(u8g2_font_helvB08_tr);
  u8g2.drawStr(100, 8, "T:");
  u8g2.drawStr(110, 8, buffer);

  if (timer > 0) { // only display a timer if one is active
    itoa(timer, buffer, 10);  // convert int to string
    u8g2.drawStr(58, 8, buffer);
  }

  u8g2.setFont(u8g2_font_helvB08_tr);
  u8g2.drawStr(0, 8, phase);

  itoa(temp_current, buffer, 10);  // convert int to string
  u8g2.setFont(u8g2_font_profont22_tr);
  u8g2.drawStr(60, 39, buffer);

  u8g2.sendBuffer();
}
